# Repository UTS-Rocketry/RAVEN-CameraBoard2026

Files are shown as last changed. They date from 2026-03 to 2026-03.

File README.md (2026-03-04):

# Raven - CameraBoard – UTS Rocketry Avionics

4c156990d7d54d2f9e3c4830885b3942_T

## Version 1.0
High-reliability camera control and downlink board built around the **STM32F405RGT6**, designed for UTS Rocketry’s flight avionics stack.  
The board provides **camera power switching**, **camera UART control**, **video downlink support**, and **CAN-based communication** with the central avionics system.

---

## Project Overview
The CameraBoard is a custom PCB designed to interface action cameras with the UTS Rocketry avionics system.  
It provides:

- **Reliable power delivery** to the camera through a load-switch architecture  
- **UART-based camera control** (start/stop recording, mode switching, etc.)  
- **Video downlink support** (placeholder until RF/video module is finalised)  
- **CAN Bus** connectivity for inter-module communication  
- **Debug UART** and activity LEDs  
- **5V → 3.3V power tree** and full onboard decoupling network  

Built around the **STM32F405RGT6**, chosen for performance, CAN support, and strong STM32 ecosystem compatibility.

---

## Key Features
- **STM32F405RGT6 MCU**
- **Camera Power Switching**
  - Load switch controlled via GPIO  
  - Local decoupling + bulk capacitance
- **Camera Control (UART)**
  - Compatible with RunCam-style UART protocols
- **CAN Bus Interface**
  - TX/RX routed to CAN transceiver  
  - Interfaces with the main flight computer
- **Video Downlink Support**
  - Reserved connector footprint  
  - Pins allocated for future video transmitter module
- **Debug Interface**
  - UART for logging  
  - Status, power, and activity LEDs
- **Power Topology**
  - Headers for 5V buck converters  
  - 3.3V rail for MCU and logic  
  - Full decoupling network following ST guidelines

## Contributors
Reed Basangan — Software Lead, UTS Rocketry
UTS Rocketry Avionics Team

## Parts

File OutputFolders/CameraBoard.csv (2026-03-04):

Reference | Qty | Value | LCSC
C14,C15 | 2 | 18p | C53084486
C1,C2,C5,C6,C7,C9,C10,C11,C13,C16,C21,C22,C26,C30 | 14 | 100nf | C49678
C8,C12,C18,C19,C23,C24,C27,C28 | 8 | 1uf | C28323
C3,C4 | 2 | 2.2uf | C19110
C31 | 1 | 4.7u | C98192
C17 | 1 | 10u | C2932476
C20,C25,C29 | 3 | 47uf | C16780
Y1 | 1 | 8mhz | C49158084
R3 | 1 | 1kr | C95781
CAN_IN1,CAN_OUT1,PowerIn1 | 3 | 2 pin Molex | C17644051
R7,R8 | 2 | 5.1kr | C27834
R1 | 1 | 10kr | C84376
R2,R5,R9,R10 | 4 | 100kr | C96346
R6 | 1 | 120r | C114245
R4 | 1 | 330r | C17630
Cam1,Cam2,Cam3 | 3 | Conn_01x03 | C131339
D2,D3 | 2 | D_Schottky | C113936
FB1 | 1 | FerriteBead | C85840
U2 | 1 | LDL1117-3.3 | C435835
J1 | 1 | Microsemi_FlashPro-JTAG-10 | C588426
D1 | 1 | NeoPixel_THT | C2827321
PowerLED1 | 1 | RLED | C965799
BootSwitch1,RSTSwitch1 | 2 | SAMZO G4R0015010 | C49393646
U4 | 1 | SN65HVD230 | C1543812
JP1 | 1 | SolderJumper_2_Open
D4 | 1 | SRV05-4.TCT | C13612
U1 | 1 | STM32F405RGT6 | C15742
U3,U5,U6 | 3 | TPS22917DBVR | C2681320
J3 | 1 | USB_C_Receptacle_USB2.0_16P | C165948
J_BUCK_IN_A1,J_BUCK_IN_B1,J_BUCK_OUT_A1,J_BUCK_OUT_B1 | 4 | ~

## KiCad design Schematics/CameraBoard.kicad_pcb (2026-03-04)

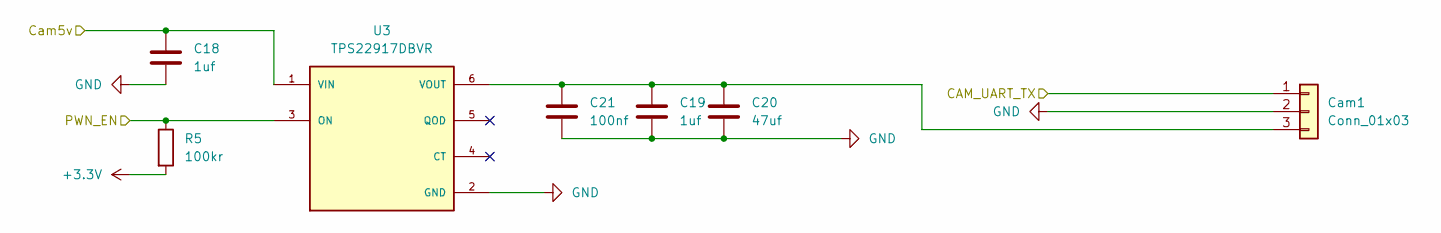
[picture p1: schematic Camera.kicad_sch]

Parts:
C18, C19: 1uf; C_0805_2012Metric_Pad1.18x1.45mm_HandSolder; LCSC C28323
C20: 47uf; C_0805_2012Metric_Pad1.18x1.45mm_HandSolder; LCSC C16780
C21: 100nf; C_0805_2012Metric_Pad1.18x1.45mm_HandSolder; LCSC C49678
Cam1: Conn_01x03; JST_PH_B3B-PH-K_1x03_P2.00mm_Vertical; LCSC C131339
R5: 100kr; R_0805_2012Metric_Pad1.20x1.40mm_HandSolder; LCSC C96346
U3: TPS22917DBVR; SOT95P280X145-6N; PARTREV B; LCSC C2681320

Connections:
+3.3V: R5.2; also elsewhere on the board
+5V: C18.1, U3.1 (VIN); also elsewhere on the board
/Camera_center/CAM_UART_TX: Cam1.1; also elsewhere on the board
/Camera_left/<NO NET>: C19.1, C20.1, C21.1, Cam1.3, U3.6 (VOUT)
/Camera_left/PWN_EN: R5.1, U3.3 (ON); also elsewhere on the board
GND: C18.2, C19.2, C20.2, C21.2, Cam1.2, U3.2 (GND); also elsewhere on the board

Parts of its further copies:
C23, C24, C27, C28: 1uf; C_0805_2012Metric_Pad1.18x1.45mm_HandSolder; LCSC C28323
C25, C29: 47uf; C_0805_2012Metric_Pad1.18x1.45mm_HandSolder; LCSC C16780
C26, C30: 100nf; C_0805_2012Metric_Pad1.18x1.45mm_HandSolder; LCSC C49678
Cam2, Cam3: Conn_01x03; JST_PH_B3B-PH-K_1x03_P2.00mm_Vertical; LCSC C131339
R9, R10: 100kr; R_0805_2012Metric_Pad1.20x1.40mm_HandSolder; LCSC C96346
U5, U6: TPS22917DBVR; SOT95P280X145-6N; PARTREV B; LCSC C2681320

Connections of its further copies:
+3.3V: R9.2, R10.2; also elsewhere on the board
+5V: C23.1, C27.1, U5.1 (VIN), U6.1 (VIN); also elsewhere on the board
/Camera_center/<NO NET>: C28.1, C29.1, C30.1, Cam3.3, U6.6 (VOUT)
/Camera_center/CAM_UART_TX: Cam2.1, Cam3.1; also elsewhere on the board
/Camera_center/PWN_EN: R10.1, U6.3 (ON); also elsewhere on the board
/Camera_right/<NO NET>: C24.1, C25.1, C26.1, Cam2.3, U5.6 (VOUT)
/Camera_right/PWN_EN: R9.1, U5.3 (ON); also elsewhere on the board
GND: C23.2, C24.2, C25.2, C26.2, C27.2, C28.2, C29.2, C30.2, Cam2.2, Cam3.2, U5.2 (GND), U6.2 (GND); also elsewhere on the board

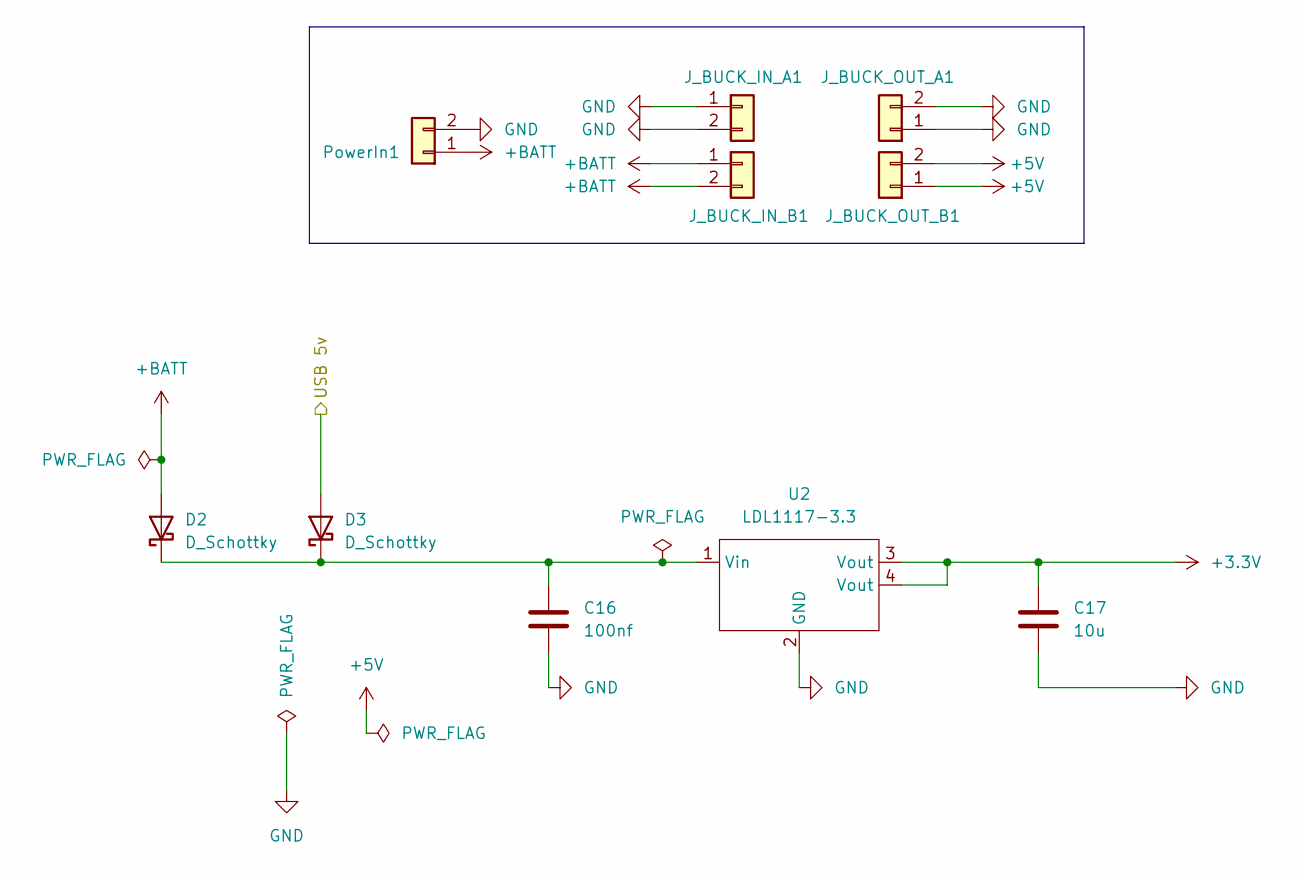
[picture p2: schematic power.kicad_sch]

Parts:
C16: 100nf; C_0805_2012Metric_Pad1.18x1.45mm_HandSolder; LCSC Part C28323
C17: 10u; C_0805_2012Metric_Pad1.18x1.45mm_HandSolder; LCSC Part C98192
D2, D3: D_Schottky; D_2114_3652Metric; LCSC C113936
J_BUCK_IN_A1: PinSocket_1x02_P2.54mm_Horizontal
J_BUCK_IN_B1: PinSocket_1x02_P2.54mm_Horizontal
J_BUCK_OUT_A1: PinSocket_1x02_P2.54mm_Horizontal
J_BUCK_OUT_B1: PinSocket_1x02_P2.54mm_Horizontal
PowerIn1: 2 pin Molex; MOLEX_26013114; LCSC C17644051
U2: LDL1117-3.3; SOT230P700X180-4N; LCSC C435835

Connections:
+3.3V: C17.1, U2.3 (Vout), U2.4 (Vout); also elsewhere on the board
+5V: J_BUCK_OUT_B1.1, J_BUCK_OUT_B1.2; also elsewhere on the board
+BATT: D2.2 (A), J_BUCK_IN_B1.1, J_BUCK_IN_B1.2, PowerIn1.1
/MCU/VBUS: D3.2 (A); also elsewhere on the board
GND: C16.2, C17.2, J_BUCK_IN_A1.1, J_BUCK_IN_A1.2, J_BUCK_OUT_A1.1, J_BUCK_OUT_A1.2, PowerIn1.2, U2.2 (GND); also elsewhere on the board
unnamed: C16.1, D2.1 (K), D3.1 (K), U2.1 (Vin)

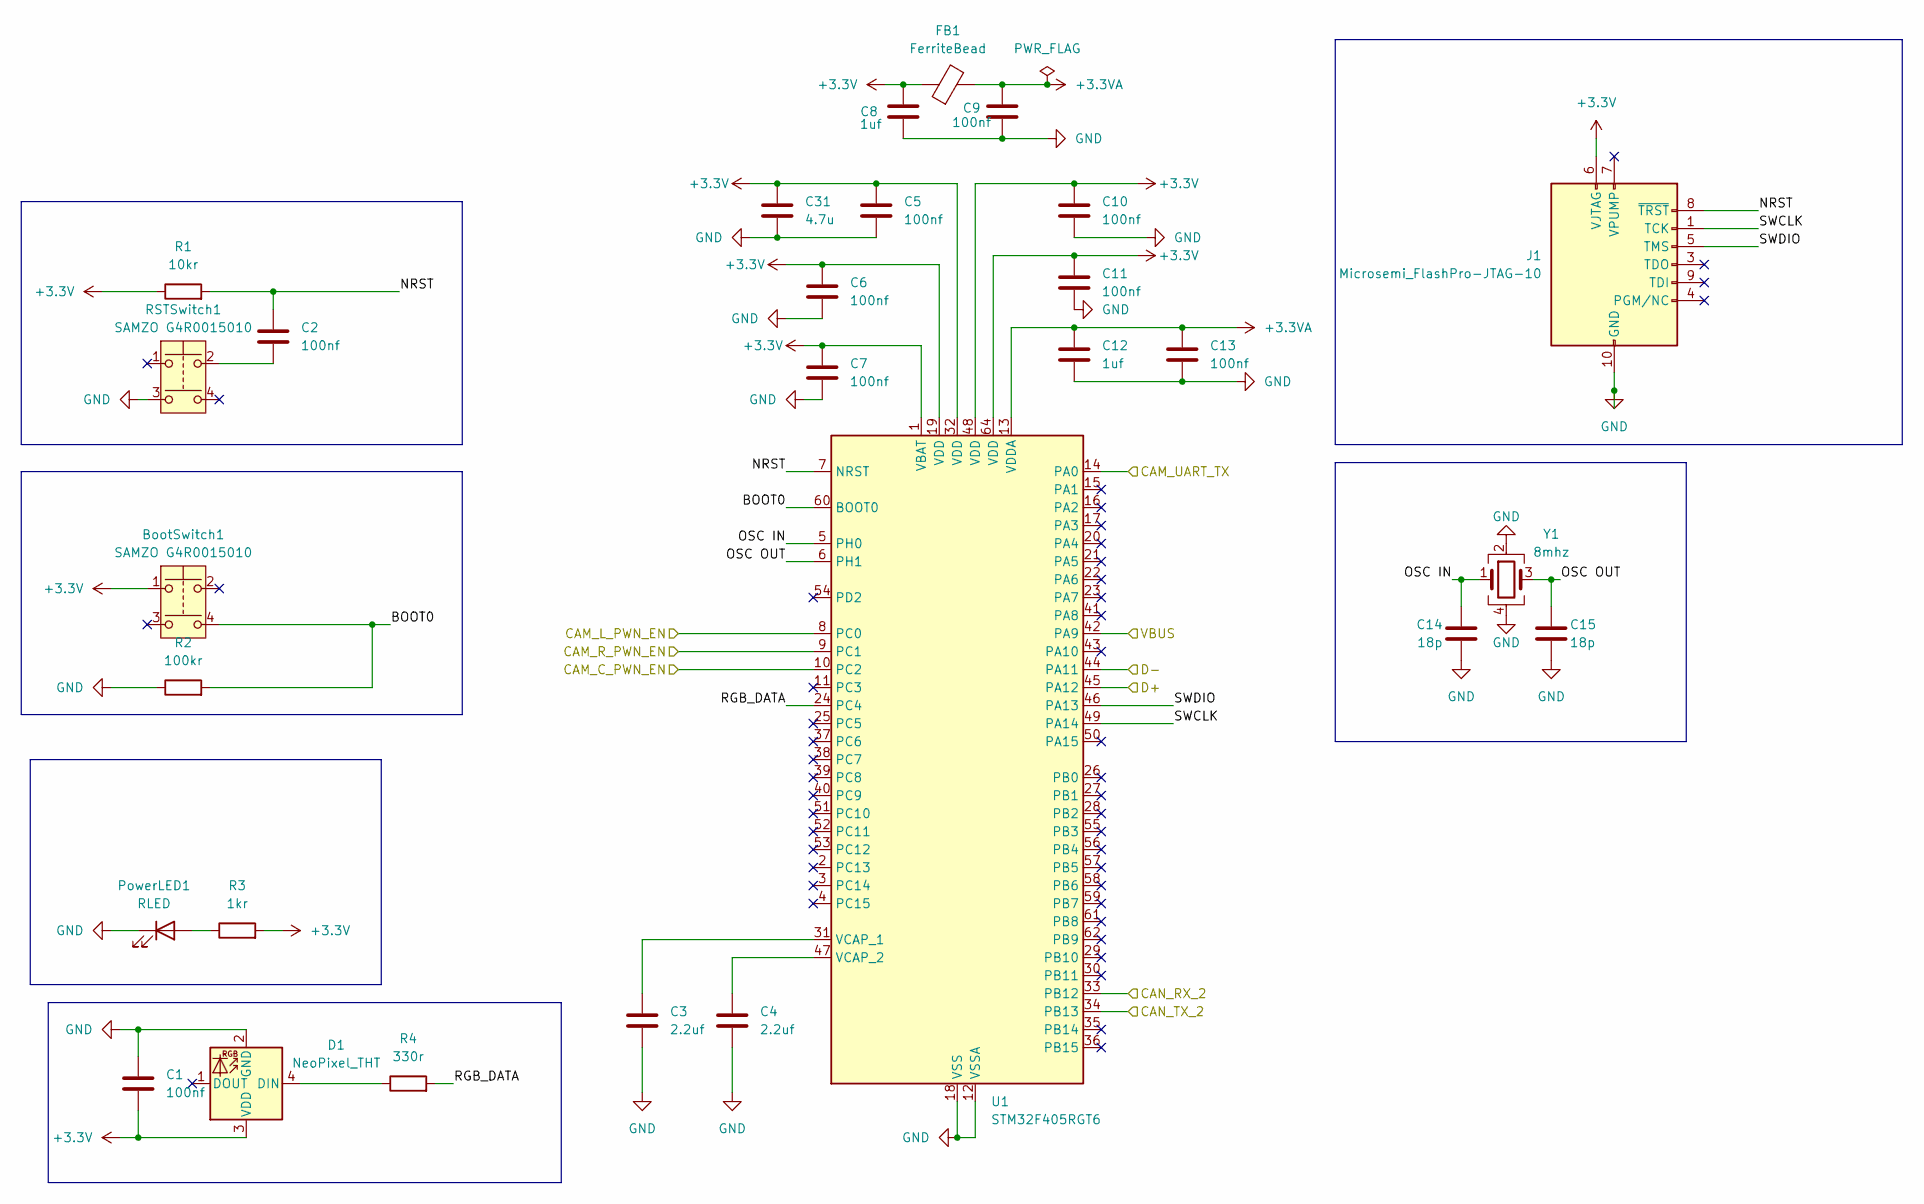
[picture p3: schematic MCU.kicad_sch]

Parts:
BootSwitch1: SAMZO G4R0015010; LCSC C49393646
C1, C2, C5, C6, C7, C9, C10, C11, C13: 100nf; C_0805_2012Metric_Pad1.18x1.45mm_HandSolder; LCSC C49678
C3, C4: 2.2uf; C_0805_2012Metric_Pad1.18x1.45mm_HandSolder; LCSC C19110
C8, C12: 1uf; C_0805_2012Metric_Pad1.18x1.45mm_HandSolder; LCSC C28323
C14, C15: 18p; C_0603_1608Metric_Pad1.08x0.95mm_HandSolder; LCSC Part C1647
C31: 4.7u; C_0805_2012Metric_Pad1.18x1.45mm_HandSolder; LCSC C98192
D1: NeoPixel_THT; LED_Kingbright_AAA3528ESGCT; LCSC C2827321
FB1: FerriteBead; R_0805_2012Metric_Pad1.20x1.40mm_HandSolder; LCSC C85840
J1: Microsemi_FlashPro-JTAG-10; CONN_7024610XX_MOL; LCSC C588426
PowerLED1: RLED; LED_0603_1608Metric_Pad1.05x0.95mm_HandSolder; LCSC C965799
R1: 10kr; R_0805_2012Metric_Pad1.20x1.40mm_HandSolder; LCSC C84376
R2: 100kr; R_0805_2012Metric_Pad1.20x1.40mm_HandSolder; LCSC C96346
R3: 1kr; R_0805_2012Metric_Pad1.20x1.40mm_HandSolder; LCSC C95781
R4: 330r; R_0805_2012Metric_Pad1.20x1.40mm_HandSolder; LCSC C17630
RSTSwitch1: SAMZO G4R0015010; LCSC C49393646
U1: STM32F405RGT6; LQFP-64_10x10mm_P0.5mm; LCSC C15742
Y1: 8mhz; Crystal_SMD_3225-4Pin_3.2x2.5mm_HandSoldering; LCSC Part C19723344

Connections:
+3.3V: BootSwitch1.1, C1.2, C5.1, C6.1, C7.1, C8.2, C10.1, C11.1, C31.1, D1.3 (VDD), FB1.1, J1.6 (VJTAG), R1.1, R3.2, U1.1 (VBAT), U1.19 (VDD), U1.32 (VDD), U1.48 (VDD), U1.64 (VDD); also elsewhere on the board
+3.3VA: C9.2, C12.1, C13.1, FB1.2, U1.13 (VDDA)
/Camera_center/CAM_UART_TX: U1.14 (PA0); also elsewhere on the board
/Camera_center/PWN_EN: U1.10 (PC2); also elsewhere on the board
/Camera_left/PWN_EN: U1.8 (PC0); also elsewhere on the board
/Camera_right/PWN_EN: U1.9 (PC1); also elsewhere on the board
/Can_transceiver/CAN_RX_2: U1.34 (PB13); also elsewhere on the board
/Can_transceiver/CAN_TX_2: U1.33 (PB12); also elsewhere on the board
/MCU/BOOT0: BootSwitch1.4, R2.2, U1.60 (BOOT0)
/MCU/D+: U1.45 (PA12); also elsewhere on the board
/MCU/D-: U1.44 (PA11); also elsewhere on the board
/MCU/NRST: C2.1, J1.8 (~TRST), R1.2, U1.7 (NRST)
/MCU/OSC IN: C14.1, U1.5 (PH0), Y1.1
/MCU/OSC OUT: C15.1, U1.6 (PH1), Y1.3
/MCU/RGB_DATA: R4.2, U1.24 (PC4)
/MCU/SWCLK: J1.1 (TCK), U1.49 (PA14)
/MCU/SWDIO: J1.5 (TMS), U1.46 (PA13)
/MCU/VBUS: U1.42 (PA9); also elsewhere on the board
GND: C1.1, C3.2, C4.2, C5.2, C6.2, C7.2, C8.1, C9.1, C10.2, C11.2, C12.2, C13.2, C14.2, C15.2, C31.2, D1.2 (GND), J1.2 (GND), J1.10 (GND), PowerLED1.1 (K), R2.1, RSTSwitch1.3, U1.12 (VSSA), U1.18 (VSS), U1.63 (VSS), Y1.2, Y1.4; also elsewhere on the board
unnamed: C2.2, RSTSwitch1.2
unnamed: D1.4 (DIN), R4.1
unnamed: PowerLED1.2 (A), R3.1
unnamed: C3.1, U1.31 (VCAP_1)
unnamed: C4.1, U1.47 (VCAP_2)

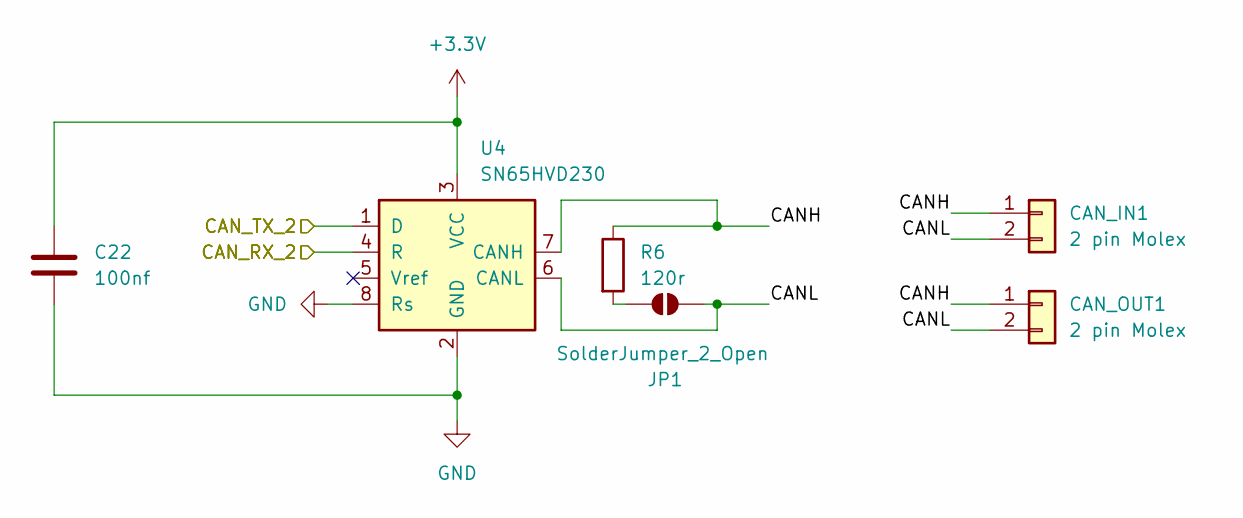
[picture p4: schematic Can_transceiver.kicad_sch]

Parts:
C22: 100nf; C_0805_2012Metric_Pad1.18x1.45mm_HandSolder; lcsc C6565120
CAN_IN1: 2 pin Molex; MOLEX_26013114; LCSC C17644051
CAN_OUT1: 2 pin Molex; MOLEX_26013114; LCSC C17644051
JP1: SolderJumper_2_Open; SolderJumper-2_P1.3mm_Open_TrianglePad1.0x1.5mm
R6: 120r; R_0603_1608Metric; lcsc C4353191
U4: SN65HVD230; SOIC-8_3.9x4.9mm_P1.27mm; lcsc C12084

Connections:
+3.3V: C22.1, U4.3 (VCC); also elsewhere on the board
/Can_transceiver/CANH: CAN_IN1.1, CAN_OUT1.1, R6.1, U4.7 (CANH)
/Can_transceiver/CANL: CAN_IN1.2, CAN_OUT1.2, JP1.2 (B), U4.6 (CANL)
/Can_transceiver/CAN_RX_2: U4.4 (R); also elsewhere on the board
/Can_transceiver/CAN_TX_2: U4.1 (D); also elsewhere on the board
GND: C22.2, U4.2 (GND), U4.8 (Rs); also elsewhere on the board
unnamed: JP1.1 (A), R6.2

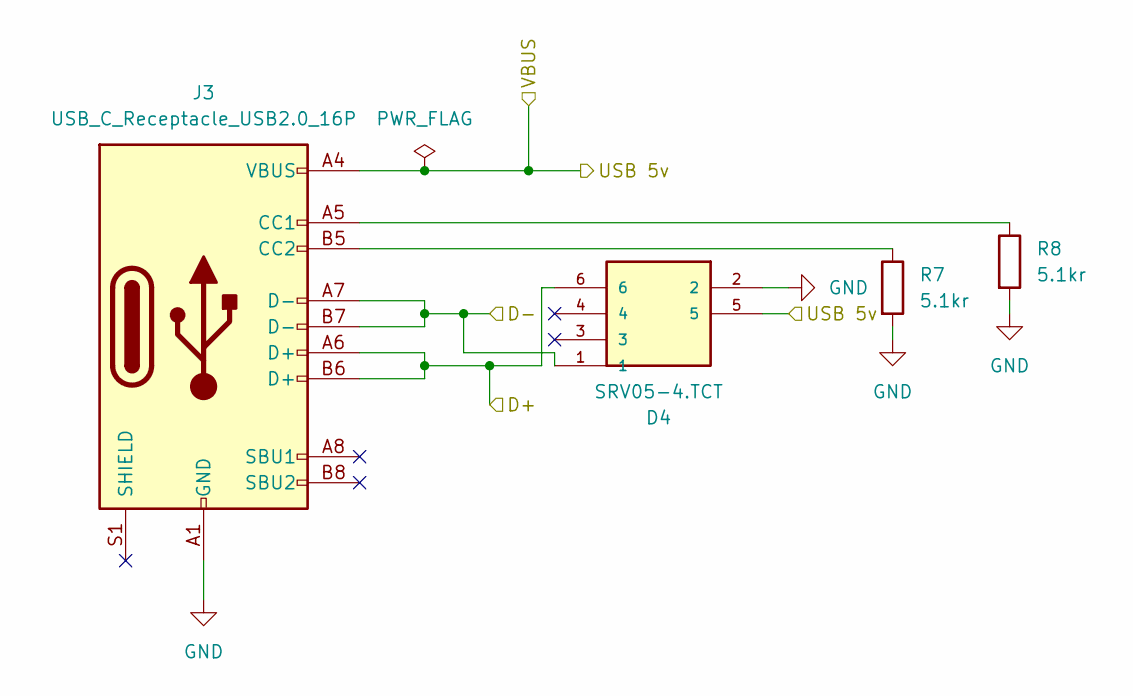
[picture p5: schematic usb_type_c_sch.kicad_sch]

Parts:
D4: SRV05-4.TCT; SOT95P280X145-6N; MOUSER_PART_NUMBER 947-SRV05-4.TCT
J3: USB_C_Receptacle_USB2.0_16P; USB_C_Receptacle_HRO_TYPE-C-31-M-12; LCSC C165948
R7, R8: 5.1kr; R_0805_2012Metric_Pad1.20x1.40mm_HandSolder; LCSC C27834

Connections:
/MCU/D+: D4.6, J3.A6 (D+), J3.B6 (D+); also elsewhere on the board
/MCU/D-: D4.1, J3.A7 (D-), J3.B7 (D-); also elsewhere on the board
/MCU/VBUS: D4.5, J3.A4 (VBUS), J3.A9 (VBUS), J3.B4 (VBUS), J3.B9 (VBUS); also elsewhere on the board
GND: D4.2, J3.A1 (GND), J3.A12 (GND), J3.B1 (GND), J3.B12 (GND), R7.2, R8.2; also elsewhere on the board
unnamed: J3.A5 (CC1), R8.1
unnamed: J3.B5 (CC2), R7.1

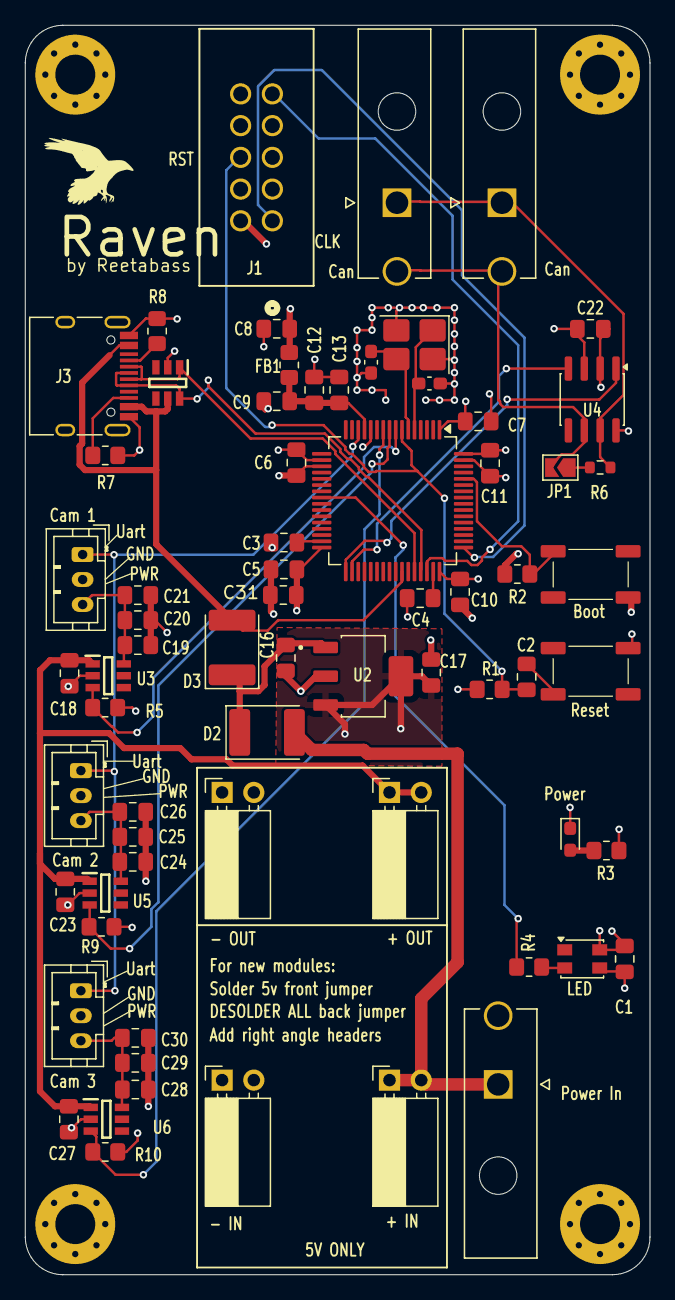
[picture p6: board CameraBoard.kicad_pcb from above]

Board: 4 copper layers, 50.0 x 100.0 mm, 69 parts (0 on the bottom side), 35 nets.

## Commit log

2026-03-02 fixed schematic and named ready for bom to order
    [CameraBoard.kicad_pcb, CameraBoard.kicad_sch, power.kicad_sch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]
2026-03-02 output files completed quote obtained
    [CameraBoard-B_Courtyard.gbr, CameraBoard-B_Cu.gbr, CameraBoard-B_Mask.gbr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]
2026-03-03 fixed buck converter routing
    [CameraBoard.kicad_pcb]
2026-03-04 final output files
    [CameraBoard-B_Courtyard.gbr, CameraBoard-B_Cu.gbr, CameraBoard-B_Mask.gbr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]
